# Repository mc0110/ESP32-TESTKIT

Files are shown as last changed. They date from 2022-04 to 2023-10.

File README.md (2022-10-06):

# ESP32-TESTKIT
KIT_Breadboard1

## Motivation
Breadboards are the best or most uncomplicated way to prototype, to test electronic circuit parts quickly and easily or to change them without a soldering iron and without losing the components.

The range of applications for ESP8266 and ESP32 is endless. It is fantastic how quickly and easily practical applications can be realised with this nice devices, which are also super easy to address via WiFi or BLE. They are also very cheap and, like many commercial products (e.g. sonoff, shelly), very reliable. 

The possibilities for using these chips are exorbitantly increased by the great ESPHOME project and also further opened up for prototyping, because it allows the otherwise additionally necessary programming to be reduced to the configuration of a single YAML file. Among other things, it offers the possibility of accessing an elegant web interface, which makes prototypes fantastically easy to implement and test, even if the final programming is to be completely changed afterwards.

** But unfortunately breadboards and ESP-DEVKITS don't really go well together. **
breadboard_issue breadboard paradox: no pin can be used

However, if you have ever tried to test your application on a breadboard with a normal TestKIT, the result is somewhat frustrating. I would call it the breadboard paradox. The grid dimension of 2.56mm fits, but all contacts are covered and therefore unusable. There is no chance to contact the individual pins of the board. The required pins must be connected to the board as cables. So you will quickly be faced with a multitude of cable connections that bring with them a high potential for errors during testing. In addition, during my experiments with the ESP32, I found that longer cables in particular can lead to problems with the voltage-supplying lines when the chip wants to establish the WiFi connection, for example, as higher current peaks can obviously occur here.

## Problem definition

This project was therefore about keeping the advantages of ESP-DEVKITS, but resolving the paradox described above and making the CPU pins on the breadboard all available. This makes it extremely convenient to supply power directly to the breadboard. Most DEVKITS have a USB micro-connector and supply the board with 5V as well as 3V3. This would be a requirement that should not be waived. The board should also ensure stable operation of the ESP32 chip, ensuring WiFi setup, etc. without brownout detection or crashes. In addition to the supply via a USB adapter, it could also be helpful to be able to use a 3V3 voltage source (Li-Ion, alkaline batteries) directly.

It has also been shown that there is a need for digital inputs and outputs in almost all circuits. For testing circuits, these should be equipped with signal LEDs to make debugging possible without additional measuring devices, auxiliary circuits, test LEDs. But the ESP32 also offers the possibility to use ADCs and DAC. In order to be able to measure voltages above 3.3V, a suitable voltage divider is needed. Here it would be good to have measurable voltages of up to 15V to cover most applications. Achieving an accuracy of 0.01V is no problem with the ESP32. The ADC functions are masterfully supported by [ESPHOME ADC](https://esphome.io/components/sensor/adc.html?highlight=adc) including the AutoRange function. 

## Provided solution

My ESP32-DEVKIT, which I would like to present here, therefore has the following features:

- USB B micro PowerInput or alternatively
- 12V PlugIn PowerInput
- Input power available as own connector for tests
- DC-DC converter to 3V3
- PGM-socket (shelly-compatible)
- RESET button and GPIO00 button
- 4x 15V ADC-ports (with voltage dividers)
  (V1:GPIO39, V2:GPIO36, V3: GPIO35, V4: GPIO34)
- 4x digital output (LED-controlled) vs. GND-level
  (O1:GPIO21, O2: GPIO22, O3: GPIO23, O4: GPIO25)
- 4x digital input (LED-controlled) vs. GND-level
  (I1:GPIO12, I2: GPIO13, I3: GPIO14, I4: GPIO15)

- all ESP-PINs available on the breadboard

Circuit diagram and board are realised in KICAD V6. The board is 2-layered.

KIT_Breadboard

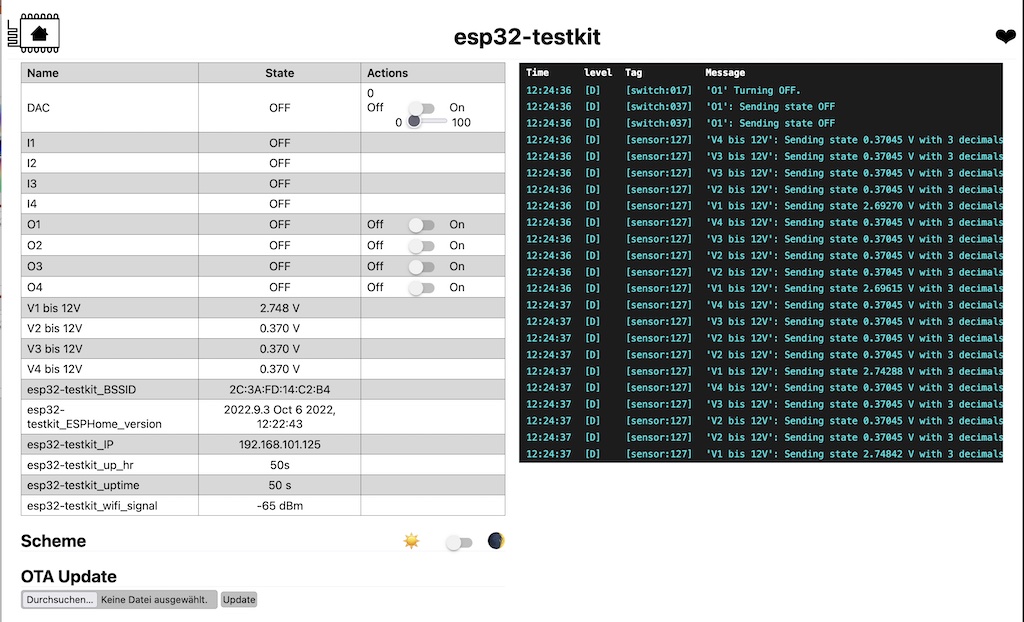
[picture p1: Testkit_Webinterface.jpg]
Example of Webinterface


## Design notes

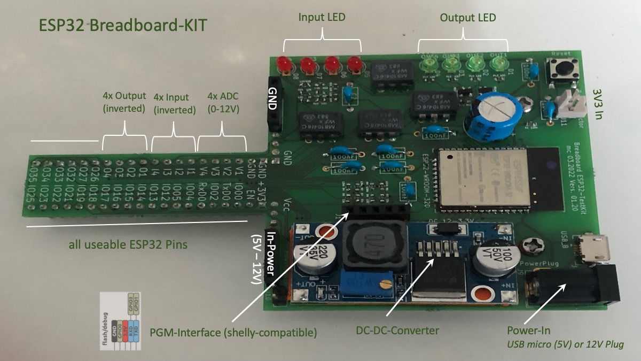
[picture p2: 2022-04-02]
KIT_description.jpg

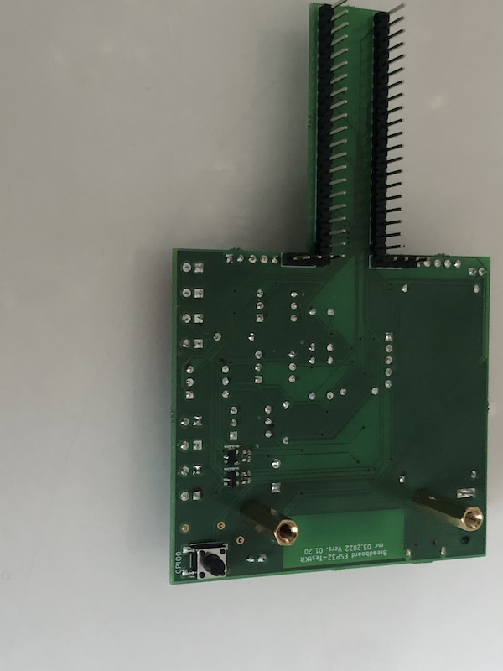
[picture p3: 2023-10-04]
KIT_Bottomside.jpg

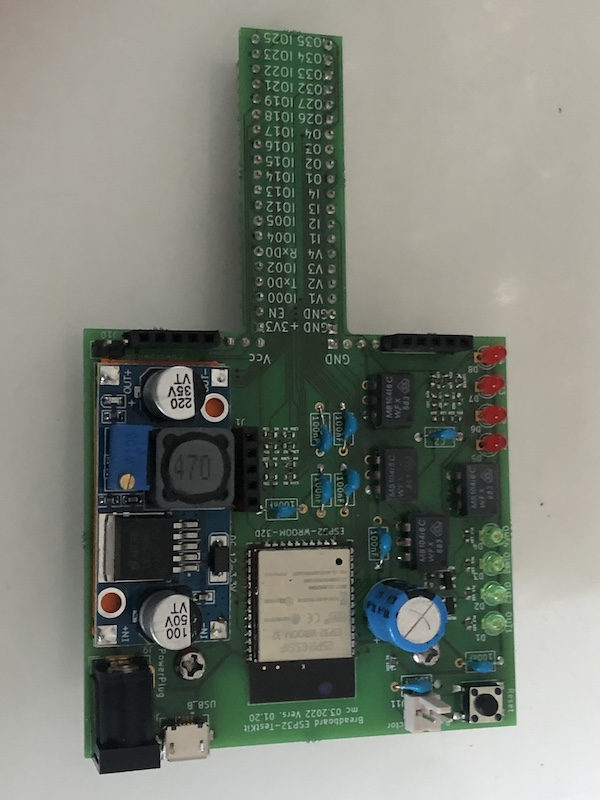
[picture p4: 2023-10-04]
KIT_UpperSide.jpg

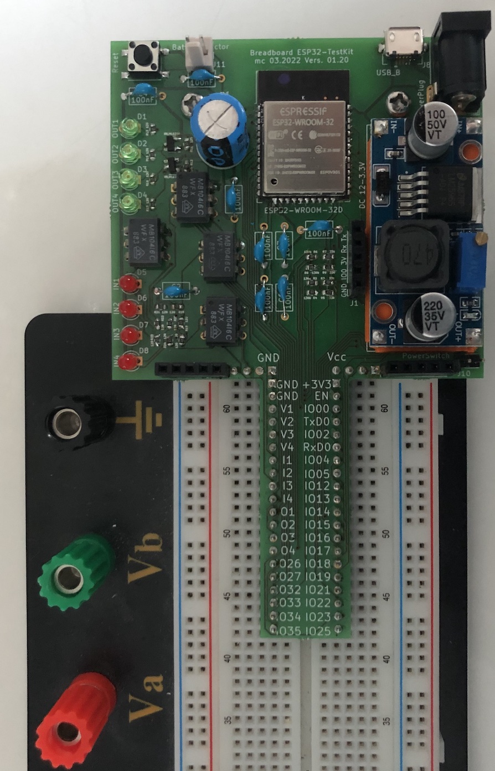
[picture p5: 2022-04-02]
KIT_Breadboard.jpg

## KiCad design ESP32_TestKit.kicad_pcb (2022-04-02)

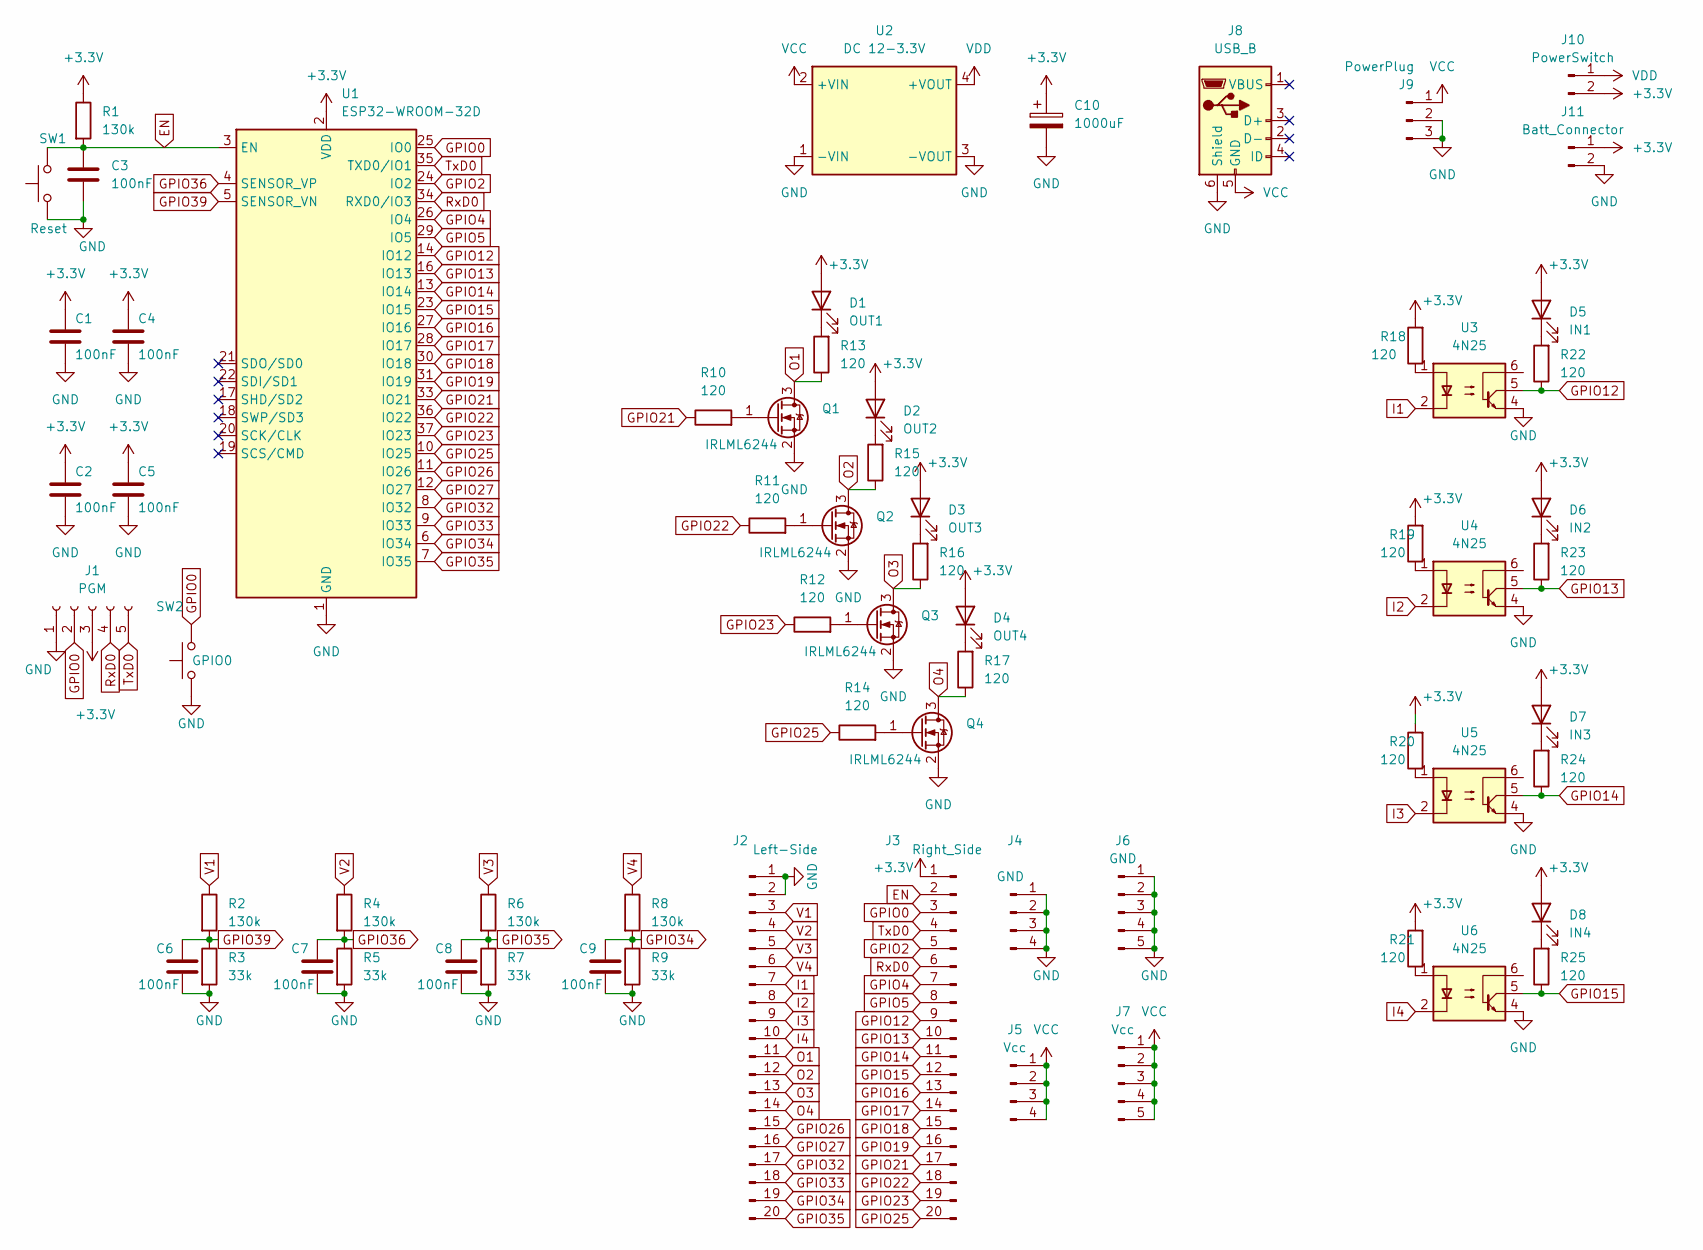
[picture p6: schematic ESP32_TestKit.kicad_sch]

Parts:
C1, C2, C3, C4, C5, C6, C7, C8, C9: 100nF; C_Axial_L5.1mm_D3.1mm_P7.50mm_Horizontal
C10: 1000uF; CP_Radial_D10.0mm_P5.00mm
D1: OUT1; LED_D3.0mm
D2: OUT2; LED_D3.0mm
D3: OUT3; LED_D3.0mm
D4: OUT4; LED_D3.0mm
D5: IN1; LED_D3.0mm
D6: IN2; LED_D3.0mm
D7: IN3; LED_D3.0mm
D8: IN4; LED_D3.0mm
J1: PGM; PinSocket_1x05_P2.54mm_Vertical
J2: Left-Side; PinHeader_1x20_P2.54mm_Vertical
J3: Right_Side; PinHeader_1x20_P2.54mm_Vertical
J4: GND; PinHeader_1x04_P2.54mm_Vertical
J5: Vcc; PinHeader_1x04_P2.54mm_Vertical
J6: GND; PinHeader_1x05_P2.54mm_Vertical
J7: Vcc; PinHeader_1x05_P2.54mm_Vertical
J8: USB_B; USB_Micro-AB_Molex_47590-0001
J9: PowerPlug; BarrelJack_GCT_DCJ200-10-A_Horizontal
J10: PowerSwitch; PinHeader_1x02_P2.54mm_Vertical
J11: Batt_Connector; PinHeader_1x02_P2.54mm_Vertical
Q1, Q2, Q3, Q4: IRLML6244; SOT-23
R1, R2, R4, R6, R8: 130k; R_0603_1608Metric
R3, R5, R7, R9: 33k; R_0603_1608Metric
R10, R11, R12, R13, R14, R15, R16, R17, R18, R19, R20, R21, R22, R23, R24, R25: 120; R_0603_1608Metric
SW1: Reset; SW_SPST_PTS645
SW2: GPIO0; SW_SPST_PTS645
U1: ESP32-WROOM-32D; ESP32-WROOM-32
U2: DC 12-3.3V; Converter_DCDC_China3A_THT
U3, U4, U5, U6: 4N25; DIP-6_W7.62mm

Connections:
+3V3: C1.1, C2.1, C4.1, C5.1, C10.1, D1.2 (A), D2.2 (A), D3.2 (A), D4.2 (A), D5.2 (A), D6.2 (A), D7.2 (A), D8.2 (A), J1.3, J3.1, J10.2, J11.1, R1.1, R18.2, R19.2, R20.2, R21.2, U1.2 (VDD)
EN: C3.1, J3.2, R1.2, SW1.2, U1.3 (EN)
GND: C1.2, C2.2, C3.2, C4.2, C5.2, C6.2, C7.2, C8.2, C9.2, C10.2, J1.1, J2.1, J2.2, J4.1, J4.2, J4.3, J4.4, J6.1, J6.2, J6.3, J6.4, J6.5, J8.6 (Shield), J9.2, J9.3, J11.2, Q1.2 (S), Q2.2 (S), Q3.2 (S), Q4.2 (S), R3.2, R5.2, R7.2, R9.2, SW1.1, SW2.1, U1.1 (GND), U1.15 (GND), U1.38 (GND), U1.39 (GND), U2.1 (-VIN), U2.3 (-VOUT), U3.4, U4.4, U5.4, U6.4
GPIO0: J1.2, J3.3, SW2.2, U1.25 (IO0)
GPIO2: J3.5, U1.24 (IO2)
GPIO4: J3.7, U1.26 (IO4)
GPIO5: J3.8, U1.29 (IO5)
GPIO12: J3.9, R22.1, U1.14 (IO12), U3.5
GPIO13: J3.10, R23.1, U1.16 (IO13), U4.5
GPIO14: J3.11, R24.1, U1.13 (IO14), U5.5
GPIO15: J3.12, R25.1, U1.23 (IO15), U6.5
GPIO16: J3.13, U1.27 (IO16)
GPIO17: J3.14, U1.28 (IO17)
GPIO18: J3.15, U1.30 (IO18)
GPIO19: J3.16, U1.31 (IO19)
GPIO21: J3.17, R10.1, U1.33 (IO21)
GPIO22: J3.18, R11.1, U1.36 (IO22)
GPIO23: J3.19, R12.1, U1.37 (IO23)
GPIO25: J3.20, R14.1, U1.10 (IO25)
GPIO26: J2.15, U1.11 (IO26)
GPIO27: J2.16, U1.12 (IO27)
GPIO32: J2.17, U1.8 (IO32)
GPIO33: J2.18, U1.9 (IO33)
GPIO34: C9.1, J2.19, R8.2, R9.1, U1.6 (IO34)
GPIO35: C8.1, J2.20, R6.2, R7.1, U1.7 (IO35)
GPIO36: C7.1, R4.2, R5.1, U1.4 (SENSOR_VP)
GPIO39: C6.1, R2.2, R3.1, U1.5 (SENSOR_VN)
I1: J2.7, U3.2
I2: J2.8, U4.2
I3: J2.9, U5.2
I4: J2.10, U6.2
unnamed: D1.1 (K), R13.2
unnamed: D2.1 (K), R15.2
unnamed: D3.1 (K), R16.2
unnamed: D4.1 (K), R17.2
unnamed: D5.1 (K), R22.2
unnamed: D6.1 (K), R23.2
unnamed: D7.1 (K), R24.2
unnamed: D8.1 (K), R25.2
unnamed: Q1.1 (G), R10.2
unnamed: Q2.1 (G), R11.2
unnamed: Q3.1 (G), R12.2
unnamed: Q4.1 (G), R14.2
unnamed: R18.1, U3.1
unnamed: R19.1, U4.1
unnamed: R20.1, U5.1
unnamed: R21.1, U6.1
O1: J2.11, Q1.3 (D), R13.1
O2: J2.12, Q2.3 (D), R15.1
O3: J2.13, Q3.3 (D), R16.1
O4: J2.14, Q4.3 (D), R17.1
RxD0: J1.4, J3.6, U1.34 (RXD0/IO3)
TxD0: J1.5, J3.4, U1.35 (TXD0/IO1)
V1: J2.3, R2.1
V2: J2.4, R4.1
V3: J2.5, R6.1
V4: J2.6, R8.1
VCC: J5.1, J5.2, J5.3, J5.4, J7.1, J7.2, J7.3, J7.4, J7.5, J8.5 (GND), J9.1, U2.2 (+VIN)
VDD: J10.1, U2.4 (+VOUT)

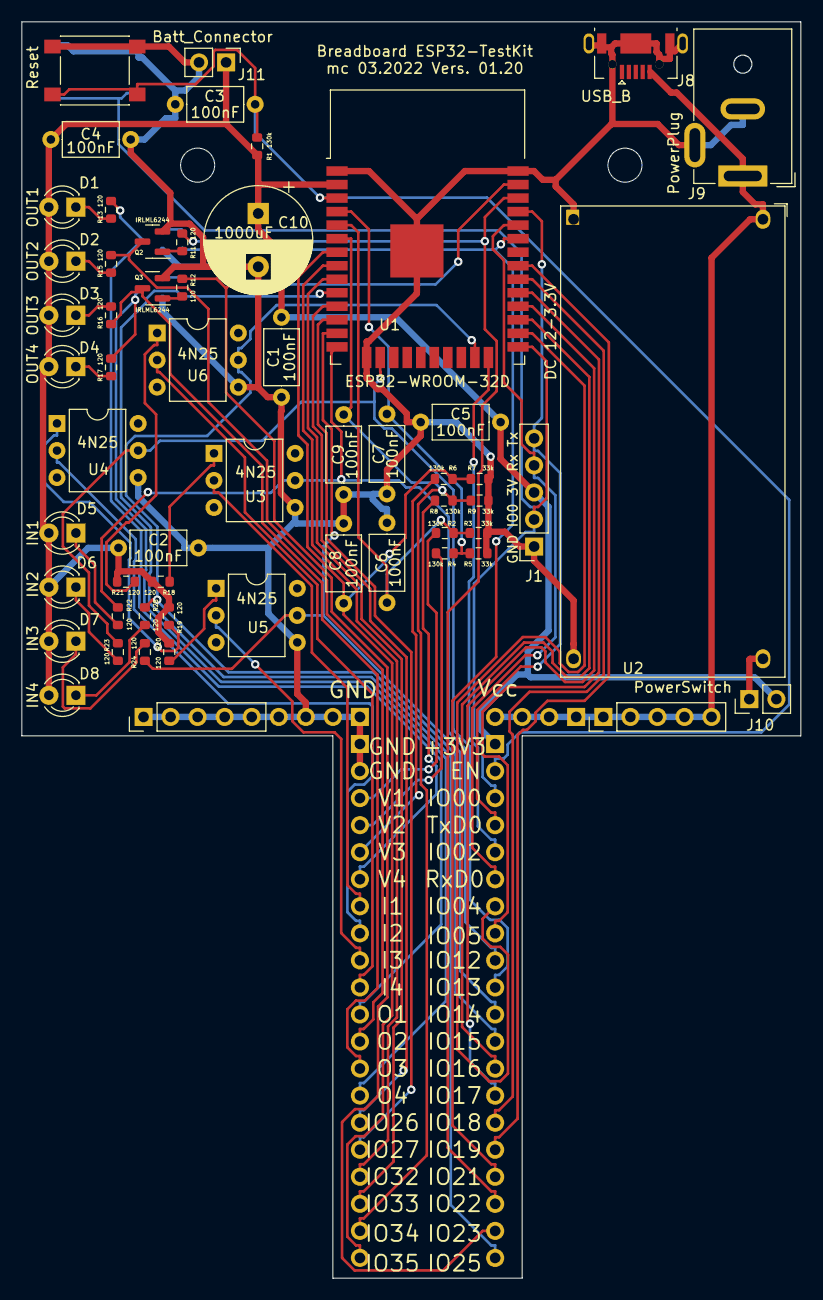
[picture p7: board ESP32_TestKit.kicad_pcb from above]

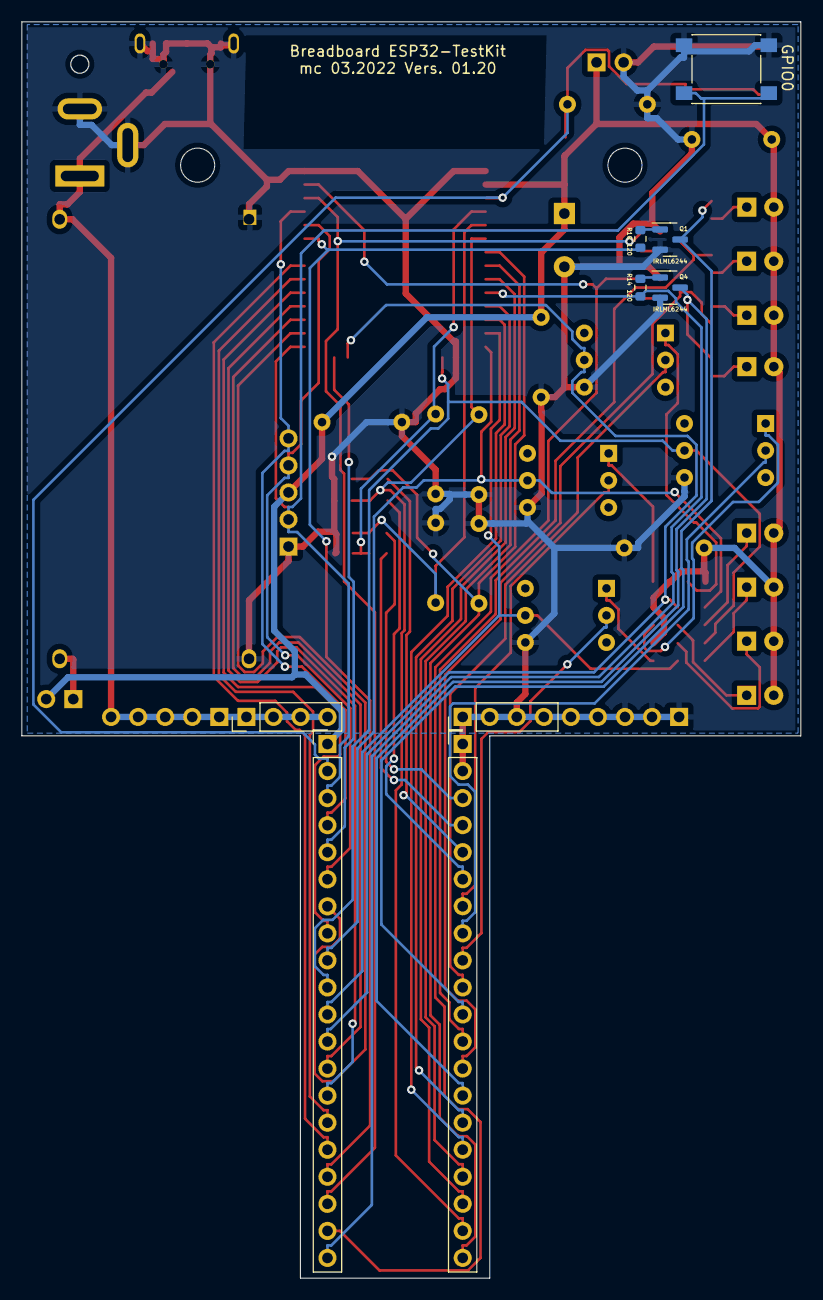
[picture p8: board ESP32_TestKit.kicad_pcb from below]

Board: 2 copper layers, 73.2 x 118.0 mm, 68 parts (9 on the bottom side), 59 nets.

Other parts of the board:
REF1, REF2: MountingHole_3.2mm_M3

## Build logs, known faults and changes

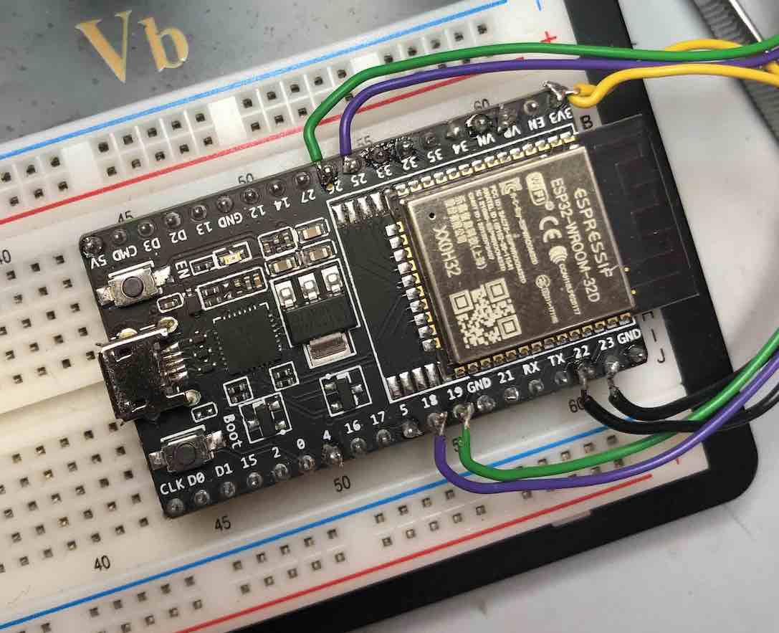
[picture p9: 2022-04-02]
breadboard_issue.jpg

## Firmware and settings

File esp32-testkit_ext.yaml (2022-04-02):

# configuration for ESP32 Testkit
# 
substitutions:
  device_name: esp32-testkit
  ui: 100ms # Update Intervall for Window-Size
  ws: '10' # Window Size -> 1s 
  se: '5' # send every -> send every 500ms
  ui1: 1s  # Update Intervall for Template-Sensors

esphome:
  name: ${device_name}
  platform: ESP32
  board: lolin32
  on_boot:
    then:
      - switch.turn_on: o1

wifi:
  ssid: "xxxxxx"
  password: "xxxxxx"

  ap:
    ssid: ${device_name}_hotspot
    password: "12345678"

captive_portal:

# Enable logging
logger:

# Enable OTA updates
ota:
  safe_mode: true
 
# Enable Web server (optional).
web_server:
  port: 80

text_sensor:
  # Expose ESPHome version as sensor.
  - platform: version
    name: ${device_name}_ESPHome_version
  # Expose WiFi information as sensors.
  - platform: wifi_info
    ip_address:
      name: ${device_name}_IP
    ssid:
      name: ${device_name}_SSID
    bssid:
      name: ${device_name}_BSSID
  - platform: template
    name: ${device_name}_up_hr
    id: uptime_human
    icon: mdi:clock-start

# Sensors with general information.
sensor:
  # Uptime sensor
  - platform: uptime
    name: ${device_name}_uptime
    id: uptime_sensor
    update_interval: 60s
    on_raw_value:
      then:
        - text_sensor.template.publish:
            id: uptime_human
            state: !lambda |-
              int seconds = round(id(uptime_sensor).raw_state);
              int days = seconds / (24 * 3600);
              seconds = seconds % (24 * 3600);
              int hours = seconds / 3600;
              seconds = seconds % 3600;
              int minutes = seconds /  60;
              seconds = seconds % 60;
              return (
                (days ? String(days) + "d " : "") +
                (hours ? String(hours) + "h " : "") +
                (minutes ? String(minutes) + "m " : "") +
                (String(seconds) + "s")
              ).c_str();
  # WiFi Signal sensor.
  - platform: wifi_signal
    name: ${device_name}_wifi_signal
    update_interval: 60s

  - platform: adc
    pin: GPIO39
    id: v39
    name: "V1 bis 12V"
    unit_of_measurement: "V"    
    accuracy_decimals: 3
    attenuation: auto
    update_interval: ${ui}
    filters:
      - sliding_window_moving_average:
          window_size: ${ws}
          send_every: ${se}
      - offset: 0
      - multiply: 4.9393939  # 1/ 33/153

  - platform: adc
    pin: GPIO36
    id: v36
    name: "V2 bis 12V"
    unit_of_measurement: "V"    
    accuracy_decimals: 3
    attenuation: auto
    update_interval: ${ui}
    filters:
      - sliding_window_moving_average:
          window_size: ${ws}
          send_every: ${se}
      - offset: 0
      - multiply: 4.9393939  # 1/ 33/153

  - platform: adc
    pin: GPIO35
    id: v35
    name: "V3 bis 12V"
    unit_of_measurement: "V"    
    accuracy_decimals: 3
    attenuation: auto
    update_interval: ${ui}
    filters:
      - sliding_window_moving_average:
          window_size: ${ws}
          send_every: ${se}
      - offset: 0
      - multiply: 4.9393939  # 1/ 33/153

  - platform: adc
    pin: GPIO34
    id: v34
    name: "V4 bis 12V"
    unit_of_measurement: "V"    
    accuracy_decimals: 3
    attenuation: auto
    update_interval: ${ui}
    filters:
      - sliding_window_moving_average:
          window_size: ${ws}
          send_every: ${se}
      - offset: 0
      - multiply: 4.9393939  # 1/ 33/153

binary_sensor:
  - platform: gpio
    pin:
      number: GPIO12
      mode:
        input: true
        pullup: true
      inverted: true
    name: "I1"
    id: i1

  - platform: gpio
    pin:
      number: GPIO13
      mode:
        input: true
        pullup: true
      inverted: true
    name: "I2"
    id: i2

  - platform: gpio
    pin:
      number: GPIO14
      mode:
        input: true
        pullup: true
      inverted: true
    name: "I3"
    id: i3

  - platform: gpio
    pin:
      number: GPIO15
      mode:
        input: true
        pullup: true
      inverted: true
    name: "I4"
    id: i4

switch:
  - platform: gpio
    id: o1
    name: "O1"
    restore_mode: ALWAYS_OFF 
    pin:
      number: GPIO21
      inverted: false
    on_turn_on:
      - delay: 2s
      - switch.turn_off: o1
    on_turn_off:
      - delay: 2s
      - switch.turn_on: o1
    
  - platform: gpio
    id: o2
    name: "O2"
    restore_mode: ALWAYS_OFF 
    pin:
      number: GPIO22
      inverted: false

  - platform: gpio
    id: o3
    name: "O3"
    restore_mode: ALWAYS_OFF 
    pin:
      number: GPIO23
      inverted: false

  - platform: gpio
    id: o4
    name: "O4"
    restore_mode: ALWAYS_OFF 
    pin:
      number: GPIO25
      inverted: false

output:
  - platform: esp32_dac
    pin: GPIO26
    id: dac_output

fan:
  - platform: speed
    output: dac_output
    name: "DAC"
